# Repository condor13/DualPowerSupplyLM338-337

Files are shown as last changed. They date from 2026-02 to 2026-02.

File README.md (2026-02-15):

Linear Power Supply for Synthesizers (+12V, -12V, +5V)
A high-quality, low-noise linear power supply designed specifically for analog synthesizers.

Features
Triple Rail Output: +12V, -12V, and +5V rails.
High Current Capability: Equipped with LM338 (5A) for positive rails and LM337 (1.5A) for the negative rail.
Adjustable Precision: Multi-turn trimmers allow for exact voltage calibration (e.g., exactly 5.00V).
Robust Protection: Includes 1N4007 back-EMF protection diodes on all stages.

Hardware Specifications
Input: Transformer with 18V-0-18V and 10V secondaries.
Regulation: LM338T (Pos), LM337T (Neg).
Thermal: Designed for external heatsink mounting with electrical isolation.

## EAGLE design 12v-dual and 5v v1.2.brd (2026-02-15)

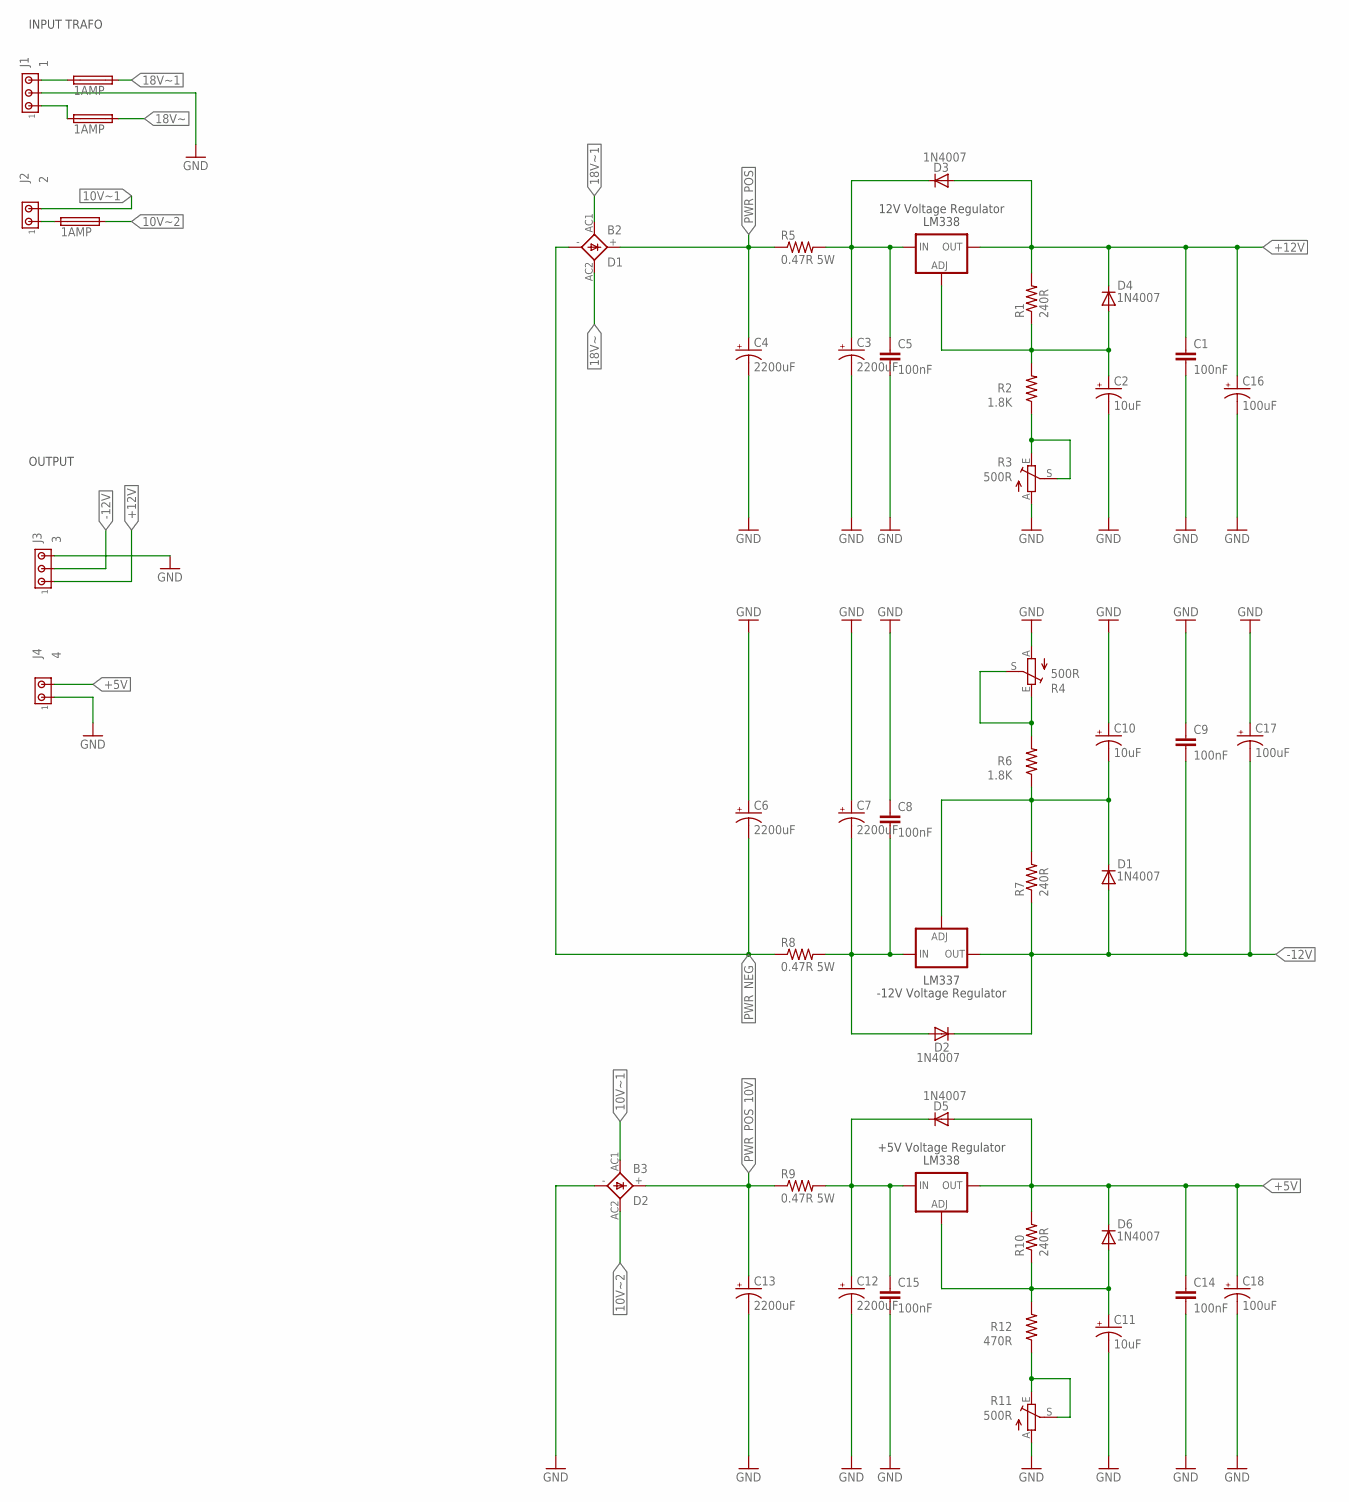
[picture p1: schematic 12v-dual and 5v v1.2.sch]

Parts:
B2: D1; FB15
B3: D2; FB15
C1, C5, C8, C9, C14, C15: 100nF; C050-025X075
C2, C10, C11: 10uF; E2-5
C3, C4, C6, C7, C12, C13: 2200uF; E5-13
C16, C17, C18: 100uF; E2-5
D1, D2, D3, D4, D5, D6: 1N4007; DO41-10
F1, F2, F3: 1AMP; SH25
IC1: LM337; 337TS
IC2: LM338; 317TS; PARTNUMBER LM317M
IC3: LM317MB; 317TS; PARTNUMBER LM317M
J1: 1; 1X3MTA
J2: 2; 1X2MTA
J3: 3; 1X3MTA
J4: 4; 1X2MTA
R1, R7, R10: 240R; 0204/7
R2, R6: 1.8K; 0204/7
R3, R4, R11: 500R; RJ9W
R5, R8, R9: 0.47R 5W; 0617/17
R12: 470R; 0204/7

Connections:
10V~1: B3.AC1, J2.2
10V~2: B3.AC2, F3.2
18V~: B2.AC2, F2.2
18V~1: B2.AC1, F1.2
18V~2: F2.1, J1.1
+5V: C14.1, C18.+, D5.A, D6.C, IC3.2 (OUT), J4.2, R10.2
+12V: C1.1, C16.+, D3.A, D4.C, IC2.2 (OUT), J3.1, R1.2
-12V: C9.2, C17.-, D1.A, D2.C, IC1.3 (OUT), J3.2, R7.1
ADJ-NEG: C10.-, D1.C, IC1.1 (ADJ), R6.1, R7.2
ADJ-POS: C2.+, D4.A, IC2.1 (ADJ), R1.1, R2.2
ADJ-POS1: C11.+, D6.A, IC3.1 (ADJ), R10.1, R12.2
GND: B3.-, C1.2, C2.-, C3.-, C4.-, C5.2, C6.+, C7.+, C8.1, C9.1, C10.+, C11.-, C12.-, C13.-, C14.2, C15.2, C16.-, C17.+, C18.-, J1.2, J3.3, J4.1, R3.A, R4.A, R11.A
unnamed: R2.1, R3.E, R3.S
unnamed: R11.E, R11.S, R12.1
unnamed: F1.1, J1.3
unnamed: F3.1, J2.1
unnamed: R4.E, R4.S, R6.2
NEG-IN: C7.-, C8.2, D2.A, IC1.2 (IN), R8.2
PWR_NEG: B2.-, C6.-, R8.1
PWR_POS: B2.+, C4.+, R5.1
PWR_POS_10V: B3.+, C13.+, R9.1
VIN: C3.+, C5.1, D3.C, IC2.3 (IN), R5.2
VIN1: C12.+, C15.1, D5.C, IC3.3 (IN), R9.2

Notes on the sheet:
+5V Voltage Regulator
-12V Voltage Regulator
12V Voltage Regulator
LM337
LM338
INPUT TRAFO
OUTPUT

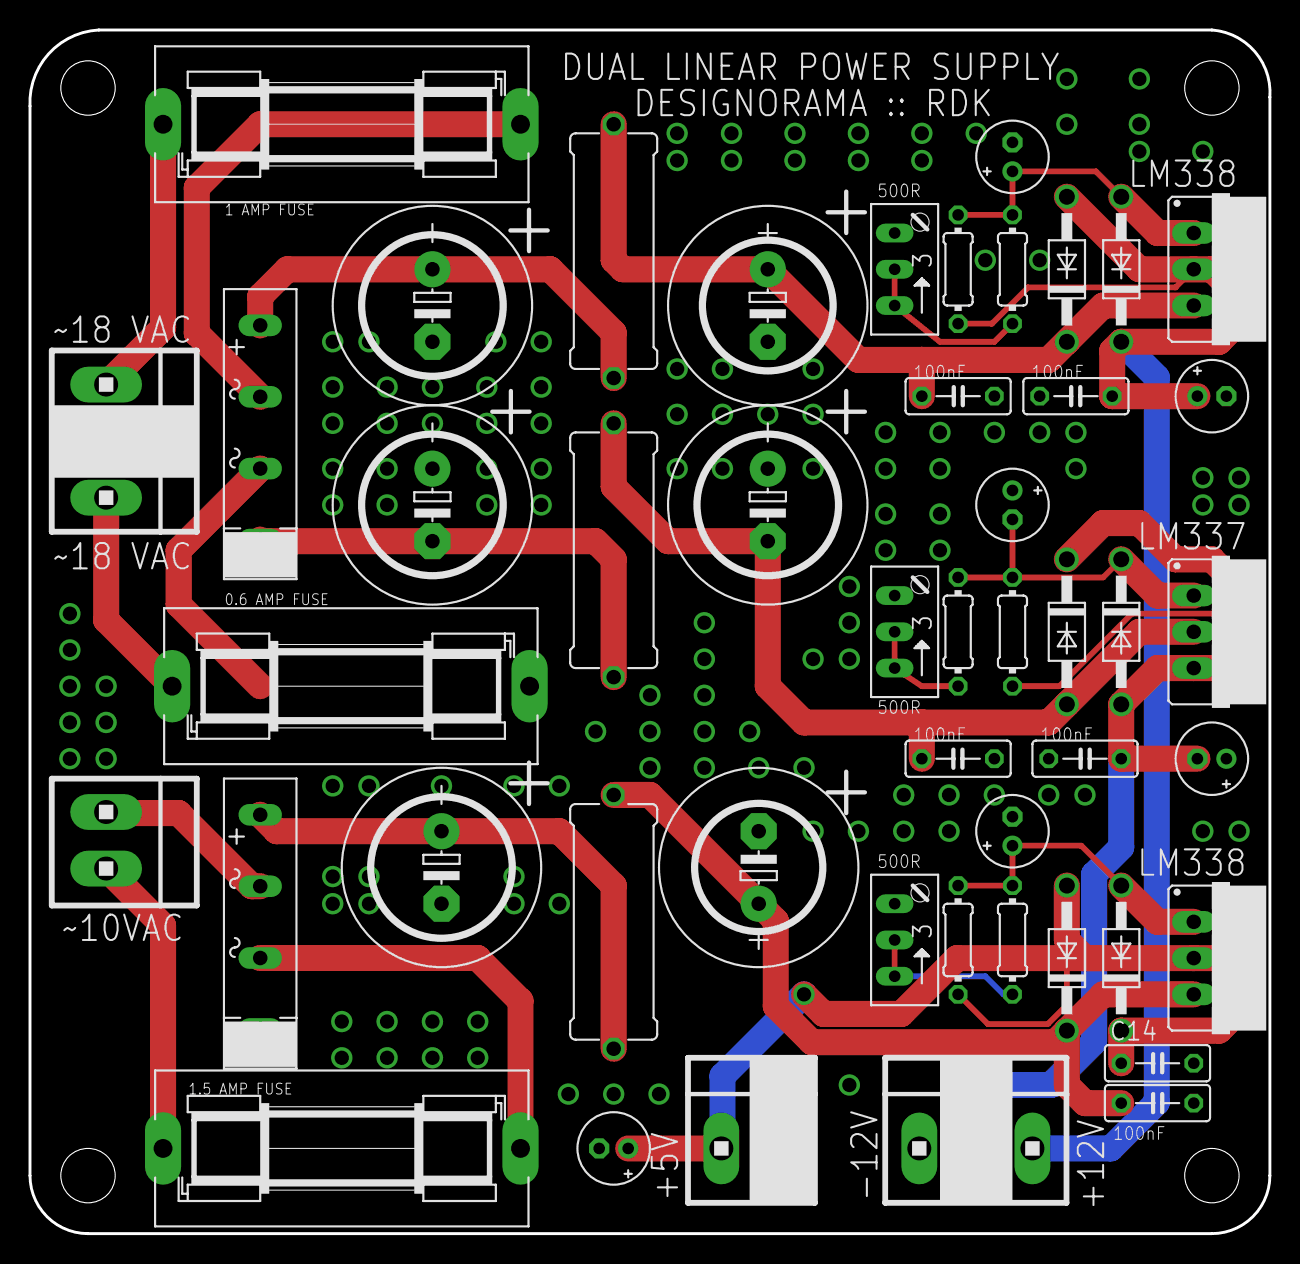
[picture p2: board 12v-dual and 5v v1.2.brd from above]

Board: 2 copper layers, 86.9 x 84.3 mm, 48 parts (0 on the bottom side), 23 nets.
